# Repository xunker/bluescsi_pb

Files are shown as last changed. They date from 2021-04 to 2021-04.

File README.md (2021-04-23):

<!-- TOC ignore:true -->
# PowerBook adapter for BlueSCSI

<!-- TOC -->

- [PowerBook adapter for BlueSCSI](#powerbook-adapter-for-bluescsi)
- [About](#about)
- [Compatibility](#compatibility)
- [Board Versions and Gerber Files](#board-versions-and-gerber-files)
  - [Future versions of the board](#future-versions-of-the-board)
- [Board Tour](#board-tour)
  - [J1 40-pin mobile SCSI connector](#j1-40-pin-mobile-scsi-connector)
  - [J2 8-pin connector](#j2-8-pin-connector)
  - [J8 50-pin desktop SCSI connector](#j8-50-pin-desktop-scsi-connector)
  - [Termination Resistors Packs and Termination Enable Jumpers J4, J5](#termination-resistors-packs-and-termination-enable-jumpers-j4-j5)
  - [MicroSD card J3 and SD Card Breakout J7](#microsd-card-j3-and-sd-card-breakout-j7)
  - [Power selection jumpers](#power-selection-jumpers)
    - [Powering board by motor power MOTORPWR](#powering-board-by-motor-power-motorpwr)
    - [Repowering board by termination power TERMPWR](#repowering-board-by-termination-power-termpwr)
    - [Powering board by USB alone](#powering-board-by-usb-alone)
  - [Activity LED D1](#activity-led-d1)
- [Bill of Materials](#bill-of-materials)
- [Caveats](#caveats)
  - [Termination](#termination)
  - [Ribbon cable should not be seated fully on connector J1 for me, at least](#ribbon-cable-should-not-be-seated-fully-on-connector-j1-for-me-at-least)
  - [Clearance](#clearance)
  - [Using the 50-pin connector at the same time as the 40-pin connector](#using-the-50-pin-connector-at-the-same-time-as-the-40-pin-connector)
- [Credits](#credits)
- [License](#license)

<!-- /TOC -->

# About

https://github.com/xunker/bluescsi_pb

This project allows you to use [BlueSCSI](https://github.com/erichelgeson/BlueSCSI) (STM32 SCSI emulator) in the Apple PowerBook, or in any other device that uses 40-pin 2.5in mobile SCSI devices.

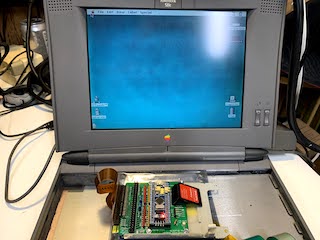
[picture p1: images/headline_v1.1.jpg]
Picture of bluescsi_pb connected to PowerBook 520c


# Compatibility

Successfully used with my PowerBook 520c using the 40-pin connector. I have **not** yet been able to make it work with my PowerBook 145, however.

Using the 50-pin connector, I have successfully used it with an Apple IIgs, a Macintosh Classic II and a Macintosh LC.

# Board Versions and Gerber Files

* [version 1.1](v1.1/) (April 2021) - current
* [version 1.0](v1.0/) (March 2021) - deprecated, not recommended

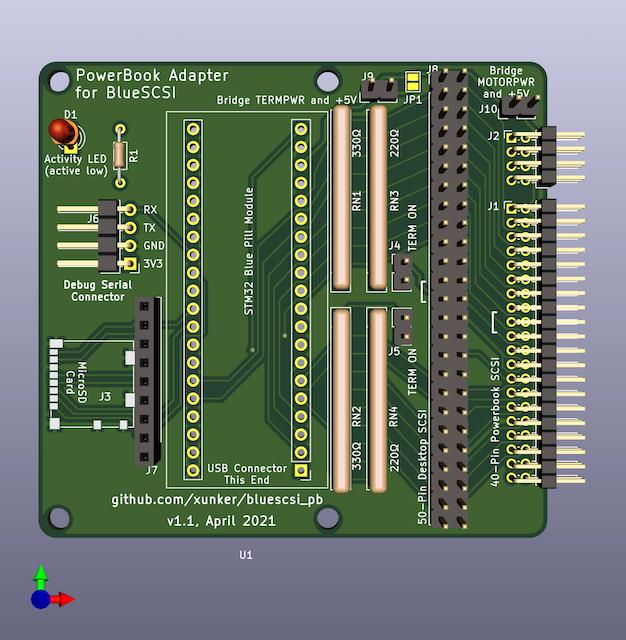
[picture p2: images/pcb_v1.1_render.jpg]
3D rendering of bluescsi_pb v1.1 board


## Future versions of the board

See [FUTURE_PLANS.md](FUTURE_PLANS.md).

# Tour of board v1.1

## J1 (40-pin mobile SCSI connector)

This is a 2.0mm, two-row, right angle header connector. It connects to the ribbon cable inside the PowerBook. Most ribbon cables have a "key pin" located at pin 17. If this is the case, you will need to break that pin off the connector on your board. The side the key is located on is indicated by the "[" symbol.

## J2 (8-pin connector)

This is also a 2.0mm, two-row, right angle header connector, located to the right of the 40-pin connector. This connector is **not required* for operation, you do not have to solder headers to it if you don't want to.

This is used in some, but not all, PowerBooks. For example, it *is* present in my PowerBook 520c but it is *not present* in my PowerBook 145.

In some systems, it is used to change the SCSI ID of the drive, trigger spin-up and provide an activity LED. Since BlueSCSI selects SCSI IDs based on filename then this is not needed.

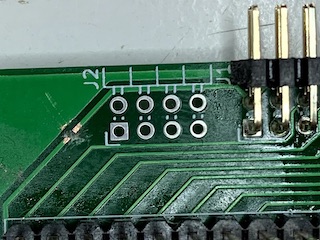
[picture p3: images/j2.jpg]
Picture of unpopulates J2 connector


## J8 (50-pin desktop SCSI connector)

This is provided to connect to a desktop SCSI connection. If you only intend to use this inside a PowerBook then this is not required.

If you do not use a shrouded connector, then you can still know the correct orientation of the SCSI cable by looking for the "[" symbol next to the connector, which represents the key cutout in a shrouded connector.

## Termination Resistors Packs and Termination Enable Jumpers (J4, J5)

Solder two 220-ohm and two 330-ohm in to the correct positions. Please note the position of pin 1, it is different on either side.

Solder 2 standard 2.54mm header pins to J4 and J5, and then cap them with a jumper/shunt to enable termination.

## MicroSD card (J3) and SD Card Breakout (J7)

Pad J3 is used for a Molex 104031-0811 MicroSD card slot.

If you do not have the correct part (or don't like soldering SMD, which is totally understandable), you can also solder 2.54mm male headers to an SD-to-MicroSD adapter and connect it to J7.

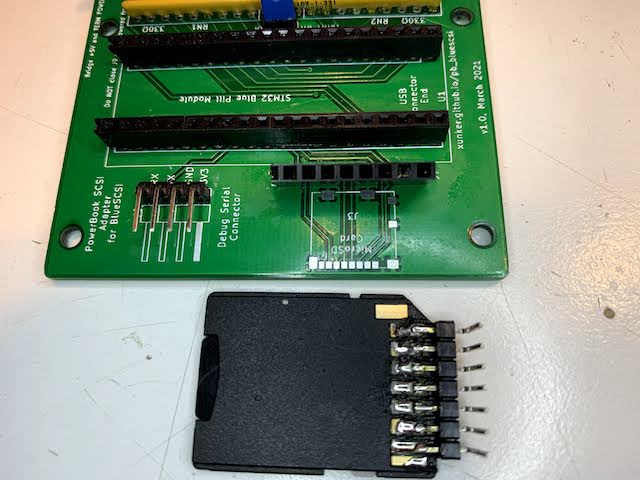
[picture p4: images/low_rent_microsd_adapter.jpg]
Picture of MicroSD connector pad and SD-to-MicroSD adapter with header pins soldered to it


## Power selection jumpers

By default the board is powered by SCSI termination power (`TERMPWR`), and is controlled by the joint JP1 (which is near J9).

### Powering board by motor power (`MOTORPWR`)

If you want to have the board be powered by +5 motor power (`MOTORPWR`) instead of `TERMPWR`, you must
* Break joint **JP1** with a small knife
* Solder a 2-pin header to **J10** and short it with a removable jumper cap

This will power the Blue Pill module from `MOTORPWR`, but *SCSI termination* will still be powered by `TERMPWR`.

### (Re)powering board by termination power (`TERMPWR`)

If JP1 is broken and you want reconnect the board back to `TERMPWR`, you must either:
* Solder a 2-pin header to **J9** and short it with a removable jumper cap

.. or ..

* Resolder **JP1**

### Powering board by USB alone

If you want to power the Blue Pill module from USB power, you must:
* Break joint **JP1** with a small knife
* Ensure that **J9** AND **J10** are **NOT** shorted

## Activity LED (D1)

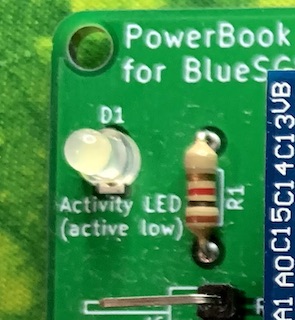
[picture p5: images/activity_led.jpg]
Picture of Disk Activity LED (D1)


This is a breakout of the built-in LED that reflects disk activity. It is the same as the LED on the Blue Pill module itself. This part is **optional** and the module will work without it.

The signal is active-low, and current-limiting resistor for the LED is on the *positive* (anode) side of the LED. This way you can tap in to the cathode (negative) pin of the LED footprint to monitor drive activity from an external device directly if you need to do that.

# Bill of Materials

See [BOM.md](BOM.md).
# Caveats

## Termination

Although documentation for the [IBM DHAS-2270](https://stason.org/TULARC/pc/hard-drives-hdd/ibm/DHAS-2270-TRAVELSTAR-270MB-2-5-SSL-SCSI2-FAST.html) drive that originally came in my PowerBook 520c claims:

> The drive does not have termination nor pull up resistors for SCSI interface

.. I have found that this adapter does not want to work as the internal drive unless you enable termination. The PB 520c *does* supply termination power to the internal drive (although it *does not* supply it to the external HDI-30 SCSI connector).

## Ribbon cable should not be seated fully on connector J1 (for me, at least)

On my PowerBook 520c, seating the drive cable fully on to connector J1 causes the BlueSCSI module to not work. I have found that leaving the ribbon cable *slightly* (like, 1mm maybe) off the connector makes the connection much more reliable. See picture below so see how much I am talking about:

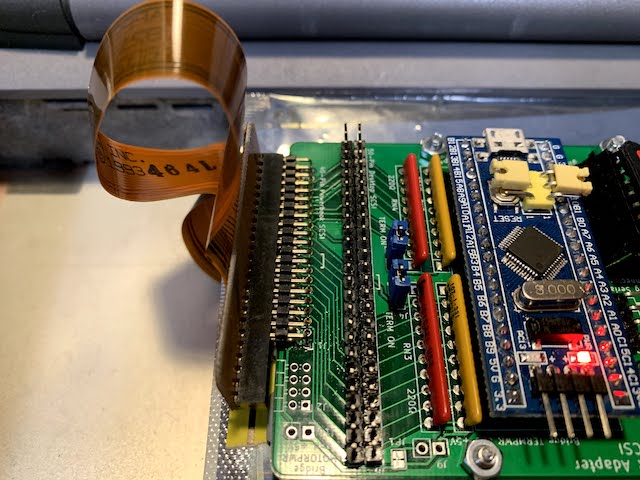
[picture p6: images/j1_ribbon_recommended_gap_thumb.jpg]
Picture of the 1mm gap between the ribbon cable and connector J1


[Click here](images/j1_ribbon_recommended_gap_thumb.jpg) for larger version of above.

## Clearance

Most SCSI PowerBooks used 17mm-tall SCSI drives. In order for this board to fit in that height, you will either need to permanently solder the STM32 module directly to the bluescsi_pb board or to use ["low-profile" female headers](https://www.adafruit.com/product/3008). If you use standard-height headers, you will need a space of 19-20mm.

Even with low-profile headers, you may have to bend the "boot select" jumpers on the top of the STM32 module off to the side.

## Using the 50-pin connector at the same time as the 40-pin connector

I recommend that you do **not** use the 50-pin and 40-pin connectors at the same time. If you know what you are doing then you are welcome to try, but please *be careful*.

# Credits

This project would not be possible without the work done by [ztto](https://github.com/ztto/ArdSCSino-stm32), [Tambo](https://twitter.com/h_koma2), [Eric Helgeson](https://github.com/erichelgeson/BlueSCSI), and many others.

The "Blue Pill" footprint was originally created by [Yet-Another-Average-Joe](https://github.com/yet-another-average-joe/Kicad-STM32).

# License

See [LICENSE.md](LICENSE.md).

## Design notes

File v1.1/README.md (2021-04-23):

# PowerBook adapter for BlueSCSI, v1.1

https://github.com/xunker/bluescsi_pb/v1.1

## April 2021

This design is the current design. It replaces [v1.0](../v1.0).

## Gerber files

Gerber files can be [found here in the gerber directory](gerber).

3D rendering of bluescsi_pb v1.1 board

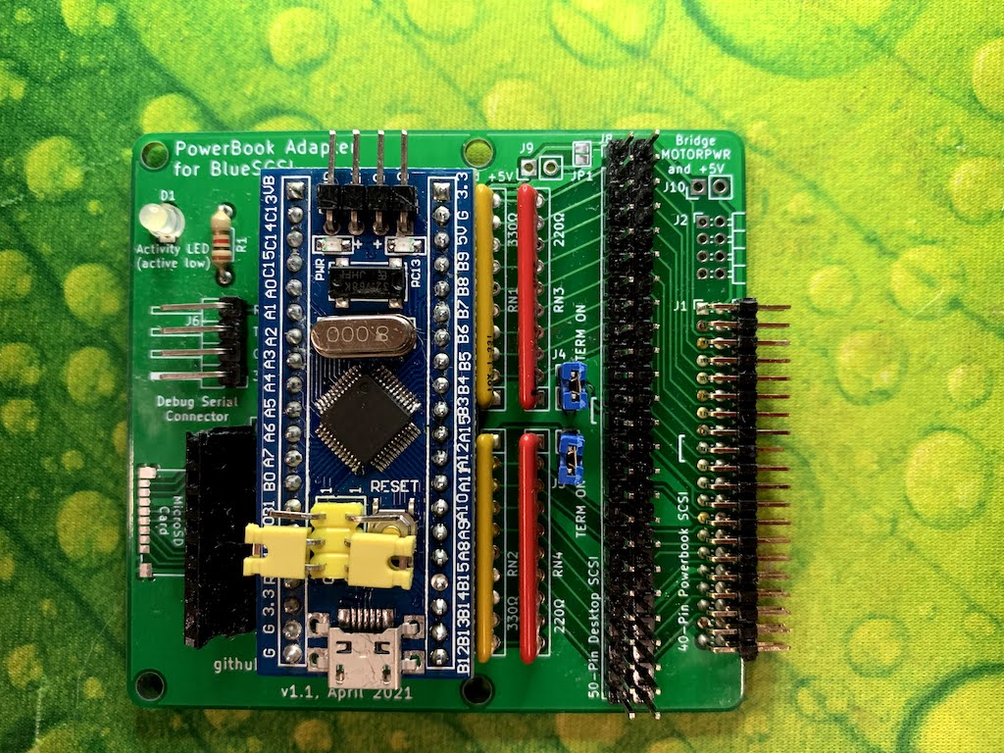
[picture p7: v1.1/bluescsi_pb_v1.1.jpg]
Picture of bluescsi_pb connected to PowerBook 520c


## Changes from v1.0

Changes in order of importance:
* Mounting hole locations adjusted so they match an actual drive
* Connect `RETURN` on 40-pin SCSI connector with signal ground
* STM32 +5 is connected to `TERMPWR` by default, via breakable jumper pad
* Separate jumpers provided for powering via `TERMPWR` or `MOTORPWR`
  - *MOTORPWR* is a separate +5v provided to run the drive motor and actuator
  - This change will be helpful for debugging power issues where *MOTORPWR* appears to be inconsistent
* Activity LED (`LED_BUILTIN`) broken-out if you want to have an external LED
* Increased `TERMPWR` trace width
* Traces and resistor packs are moved farther away from mounting holes to avoid potential shorts
* Back silkscreen marks location of the key pin (17) within the 40-pin connector
* Moved legends for J1, J2 and J8 so they are next to pin 1 on their respective connectors
* Corners rounded more
* Numerous changes to the routing of traces
* Shorten board by about 5mm
  - This is the shortest practical length to maintain all four screw holes

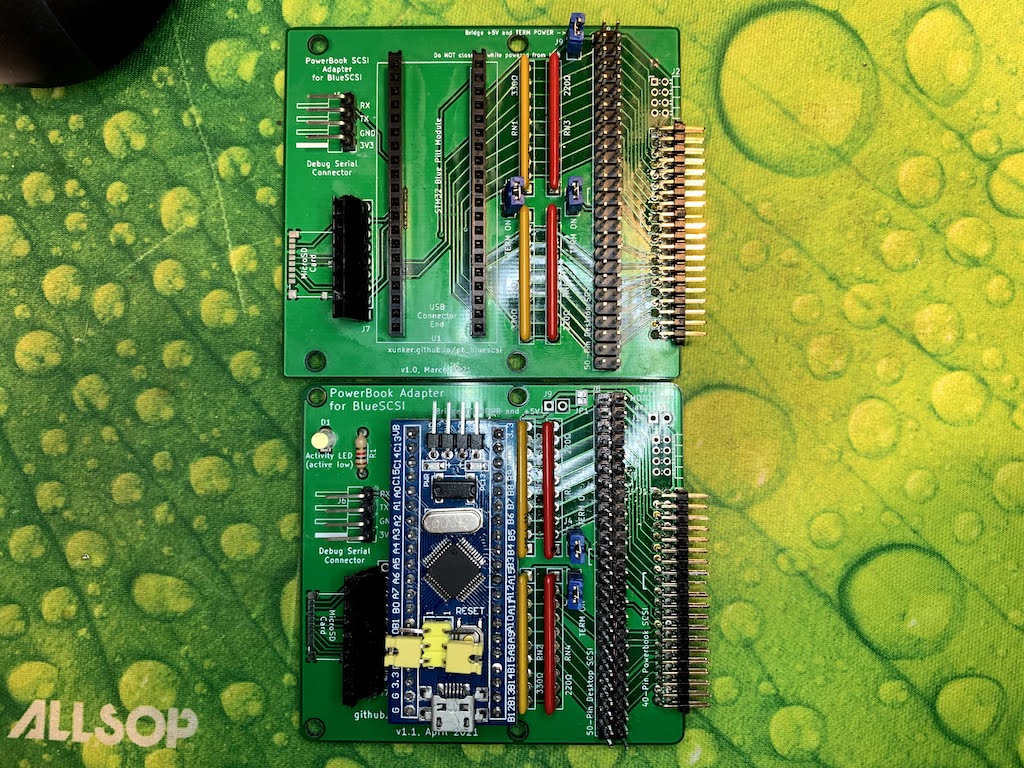
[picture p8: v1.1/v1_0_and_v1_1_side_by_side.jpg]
v1.0 and v1.1 side-by-side to show differences


## Comparison with 2.5in drive

A 2.5 inch SCSI drive is 100mm x 70mm. This version of bluescsi_pb is 72mm x 67mm, or 77mm x 67mm once the 40-pin connector is attached.

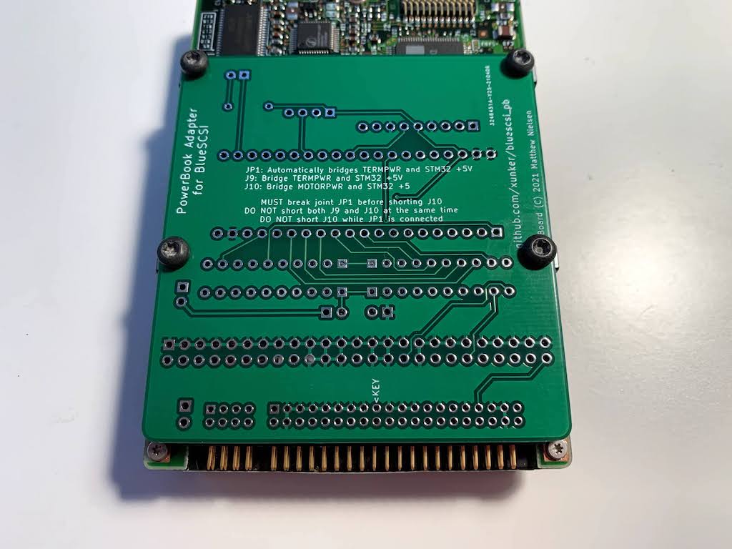
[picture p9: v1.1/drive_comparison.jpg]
Picture of bare bluescsi_pb board attached to bottom of 2.5in SCSI drive to show size differences


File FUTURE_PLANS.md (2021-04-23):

# Future plans for PowerBook adapter for BlueSCSI
# April 2021

https://github.com/xunker/bluescsi_pb/FUTURE_PLANS.md

[v1.1](v1.1) is working well so I don't expect any majour changes for a while.

## v1.2 (possible maintenance version)

Plans for a v1.2 (maintenance) may include:

* Jumper to toggle the activity LED
  - So you can solder the LED and resistor, but disable it later if you prefer
* Break out power LED
  - Provide a power LED (and a jumper toggle) breakout if an external power LED is desired
* Replace J4 & J5 with DIP switches or a single DPDT switch

## v2.0 (possible full redesign)

If I continue to develop project in the future, I plan on a full redesign.

* Use termination ICs instead of resistors
  - Lower power consumption
  - More accurate termination voltage
  - Switchable termination resistance (110-ohm or 2.5k-ohm) for short busses
* Attach J1 & J2 via the PCB edge to make it more like how an actual hard drive connects
* Less-expensive Micro SD card slot
* Automatic switching between TERMPWR, MOTORPWR or USB Power

If I want to fork the actual BlueSCSI firmware, I would like to add:

* Separate LEDs for read and write activity
* Read TERMPWR and MOTORPWR voltages and report them on the debugging connector
* LEDs to indicate with SCSI ID is being accessed
* Support OLED debugging display

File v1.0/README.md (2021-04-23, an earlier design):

# PowerBook adapter for BlueSCSI, v1.0

https://github.com/xunker/bluescsi_pb/v1.0

## March 2021

## Deprecation Notice

This design is deprecated and should no longer be used. Please [see v1.1 instead](../v1.1).

## Gerber files

Gerber files can be [found here in the gerber directory](gerber).

## Notes

First version. 50-pin-SCSI, termination and SD card worked first time, right out of the gate. However, problems:

* The screw holes are slightly too far in from edges
* `RETURN` lines are not connected to signal ground
* Can only power STM32 from `MOTORPWR` *or* USB, no option to power it from from `TERMPWR` alone
* No option to disconnect STM32 from *both* `TERMPWR` and `MOTORPWR` power and use USB power alone without backfeeding

If you choose to use this board design, **please do the following**:
* break the `MOTORPWR` trace, as seen in [this image](../images/j2.jpg)
* Solder a wire from any ground pin to one of the `RETURN` pins (number 3, 4, 37 or 38) of `J1`. These are 1 column in from each edge, and and connected together. They are next to the `MOTORPWR` pins, the trace you broke above.
* Ensure J9 ("bridge +5v and term power") is always shorted/jumped

Why the modifications? the `MOTORPWR` pins do not appear to be working the way I expect. The power was being disconnected at unexpected times and I could not see a pattern. Maybe it is a power-saving feature? Until I figure it out and update the board design, I recommend you power the device from `TERMPWR` as usual.

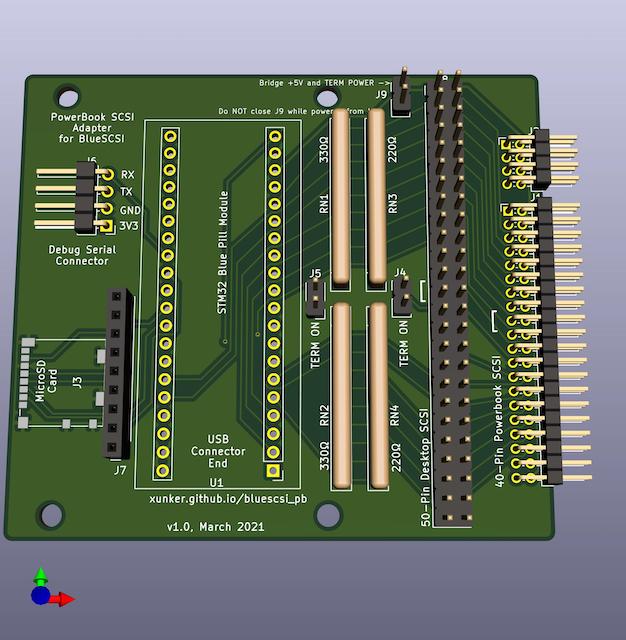
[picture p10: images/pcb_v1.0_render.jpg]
3D rendering of bluescsi_pb v1.0 board


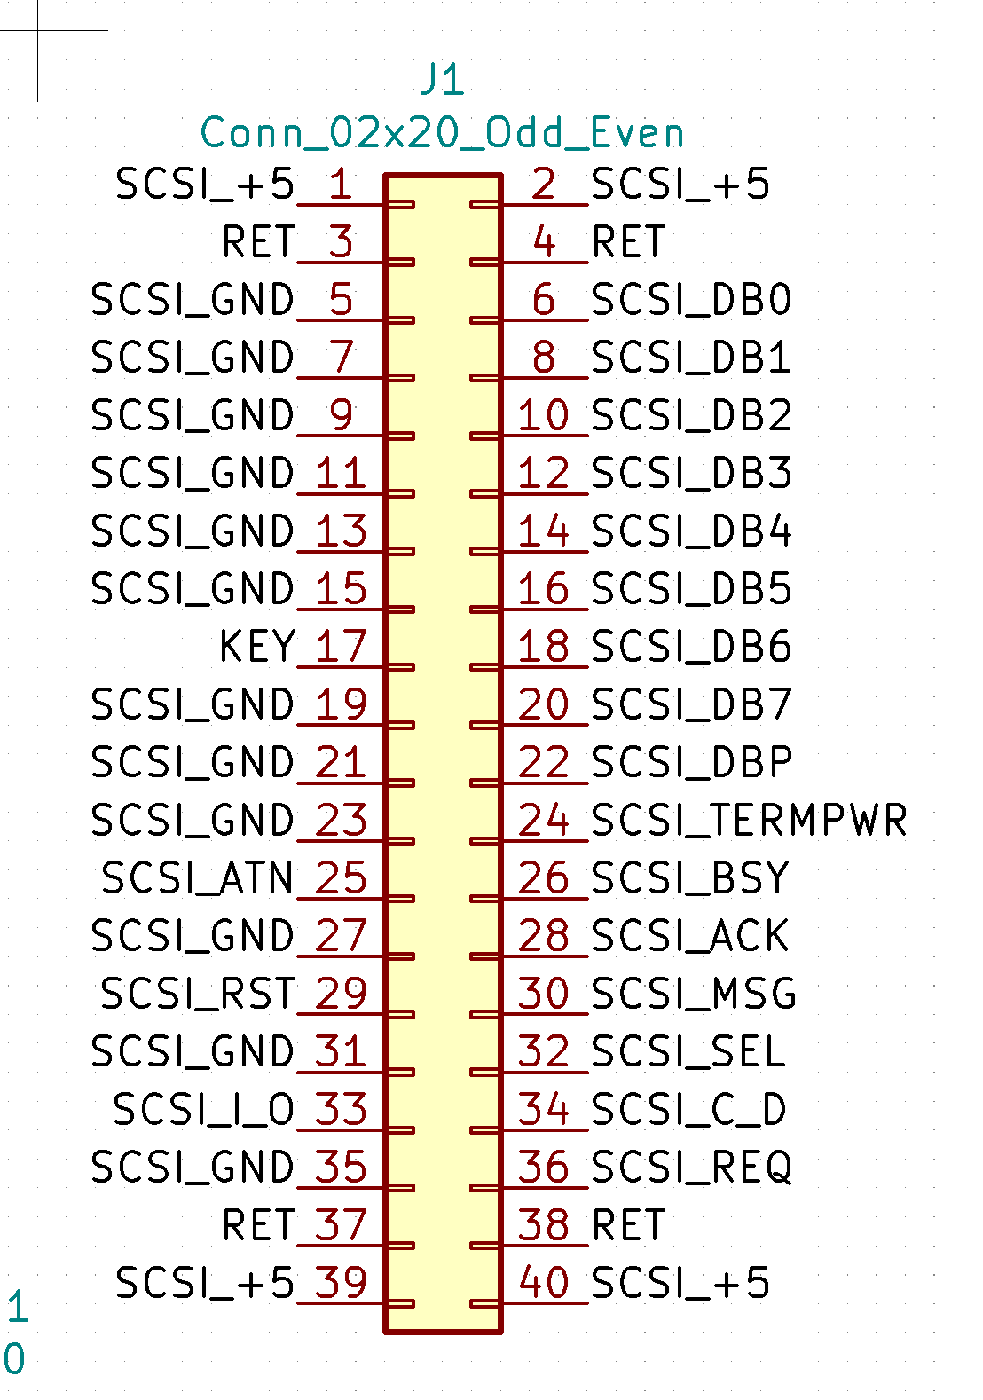
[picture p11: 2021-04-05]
images/j1_40_pin_scsi_pinout.png

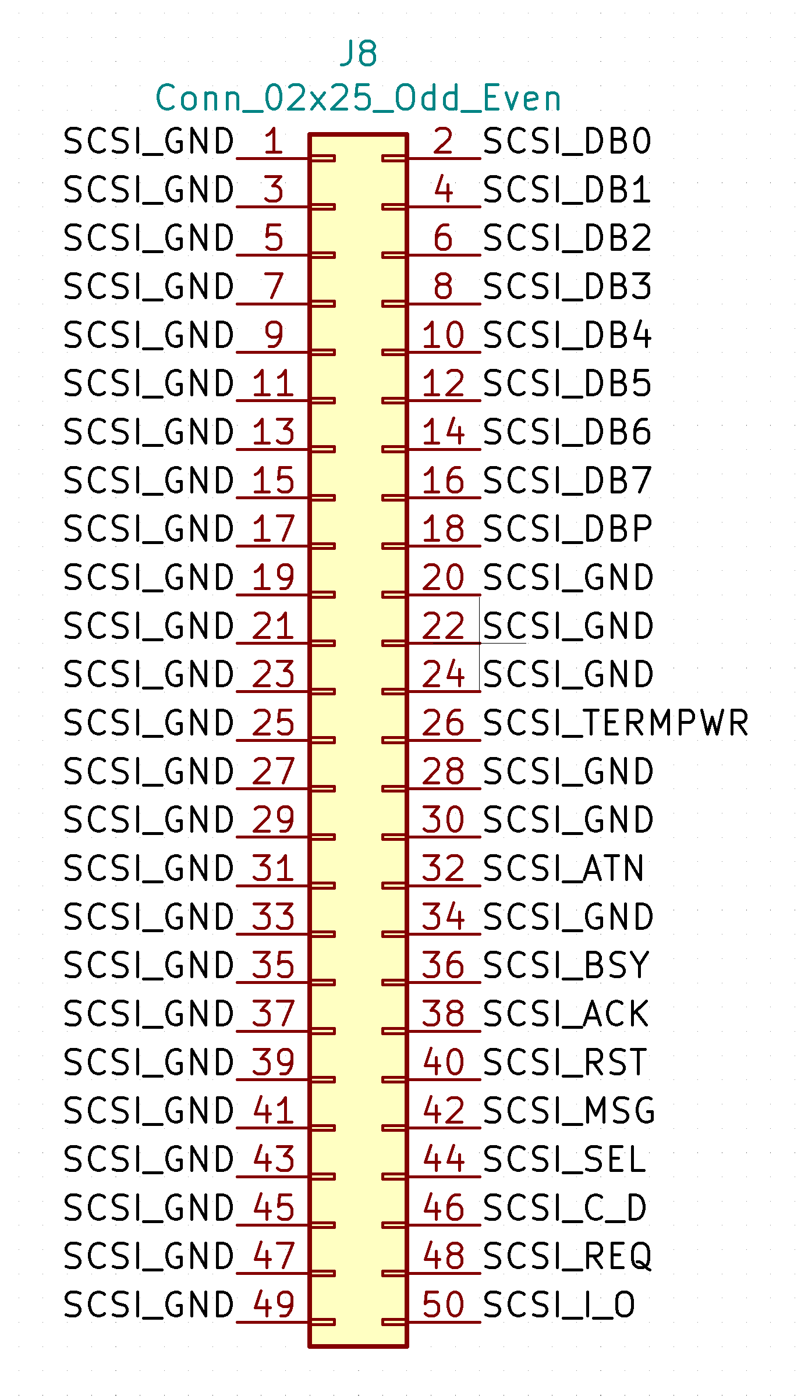
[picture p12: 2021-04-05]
images/j8_50_pin_scsi_pinout.png

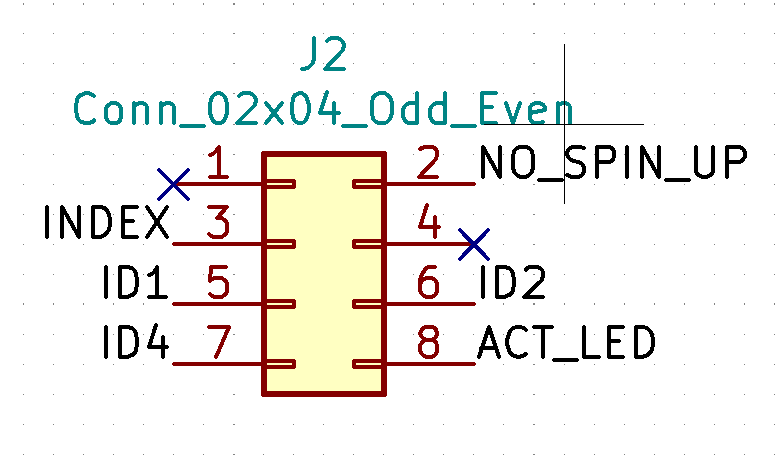
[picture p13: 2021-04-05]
images/j2_pinout.png

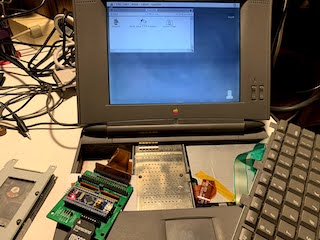
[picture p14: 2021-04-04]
images/headline_v1.0.jpg

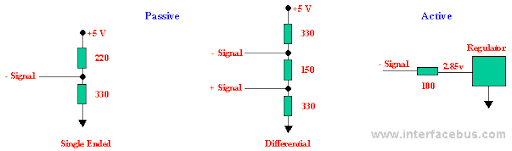
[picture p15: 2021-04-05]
images/scsi_terminator_styles.png

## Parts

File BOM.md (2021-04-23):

# Bill of Materials for PowerBook adapter for BlueSCSI

https://github.com/xunker/bluescsi_pb/BOM.md

To assemble v1.1 the board, you will need the following components:

## Required

Quantity | Thing | Example Part Number
---------|-------|--------------------
1        | An STM32 "Blue Pill" module and a way to program it with the [BlueSCSI](https://github.com/erichelgeson/BlueSCSI) firmware |
2        | 330 Ohm Resistor Network in SIP-10 package | Bourns 4610X-101-331
2        | 220 Ohm Resistor Network in SIP-10 package | Bourns 4610X-101-221
1        | MicroSD Card connector (or use SD-to-MicroSD adapter [as shown here](README.md#microsd-card-j3-and-sd-card-breakout-j7)) |  Molex 104031-0811
1        | 2x20 right-angle **2mm** header for connector J1 |
2        | 1x2 header pins for the termination jumper connectors J4 and J5 |
2        | Jumpers (aka jumper caps, shunts, or shorts) for J4 and J5 |

## Optional

Quantity | Thing
---------|-------
1        | 1x4 2.54mm right-angle header for debugging connector
2        | 1x2 header pins for the power selection jumper connectors J9 and J10
1        | 2x25 2.54 header pins for 50-pin desktop SCSI connector J8
1        | LED for D1
1        | Resistor (R1) for LED, any value from 330 ohms to about 1.8k ohms will work
2        | ["low-profile" female headers](https://www.adafruit.com/product/3008) if you do not want to permanently solder the Blue Pill board

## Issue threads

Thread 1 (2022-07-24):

Powerbook 160 + Bluescsi

Wawavoun, 2022-07-24:
Hello,

I have replaced the internal scsi drive of a Powerbook 160 with a Bluescsi.

A have a SD memory with 3 active images that works very well into a standard Bluescsi (the one for scsi flat cable) connected to the Powerbook scsi expansion port.

If I put this SD memory into the internal Bluescsi the boot become hazardous.
Sometime (often after a reset with the rear switch) the Powerbook book and then everything seems to okay.
Sometime (generally after power on) the Powerbook wont boot.
We can see he try each image and finally play the 4 notes dead sound.

If I disable 2 of the 3 images just leaving a bootable one then the Powerbook boot well everytime ! So I am salvaged...

But it could be handy to work with multiple images. Any idea will be appreciated !

Regards.
Philippe

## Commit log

2021-04-05 Add v1.1 files
    [bluescsi_powerbook-B_Cu.gbr, bluescsi_powerbook-B_Mask.gbr, bluescsi_powerbook-B_SilkS.gbr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]
2021-04-05 Update readme with board v1.1 changed and details
2021-04-20 Fix motorpwr/termpwr typo
2021-04-22 Added bill of materials
2021-04-23 Move details about each version to separate files. Move future plans to separate file. Move BOM to separate file. Add more detail and pictures to v1.1.
